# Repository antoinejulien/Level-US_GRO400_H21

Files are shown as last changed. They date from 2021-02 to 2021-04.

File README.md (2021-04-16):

# Level_US_GRO400_H21
This is an opensource project made by a team of undergratuate students from Sherbrooke University. This project is basically a self-leveling platform controled with an embedded system. Our purpose is to create a platform that will automatically balance itself according to the acceleration applied. For example, this project could be applied on boat's tables that could have to follow big waves movements. The table could then automatically balance so nothing would be spilled. We are also working on a manual mode that could allow full user control. This feature is still in progress.

## READMEs
We chose to create a README for every major section. This way, information is separated and easier to find. You can always click the next few links to get directly there :
  - [Code README](Code/README.md)
  - [Electronics README](Electronics/README.md)
  - [Mechanics README](Mechanics/README.md)

## Final prototype
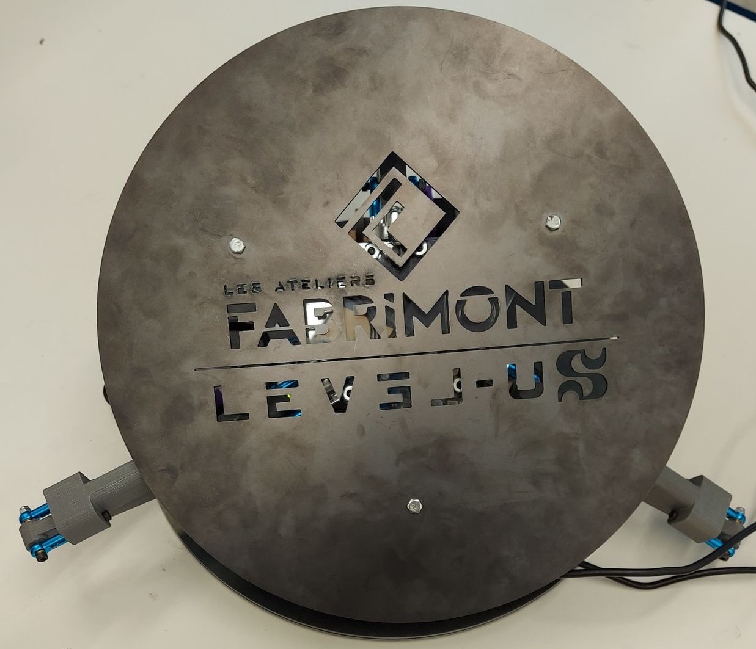
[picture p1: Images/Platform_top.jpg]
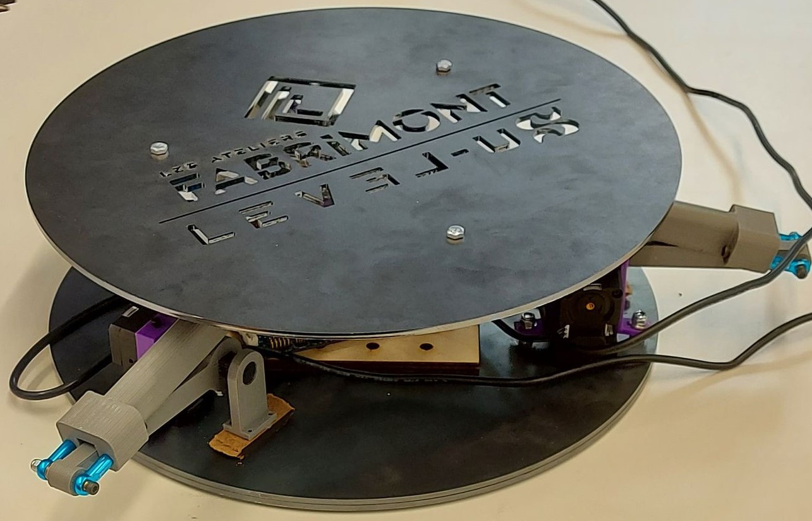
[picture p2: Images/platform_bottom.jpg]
 

## How to install the Python virtual environment (on Windows)

1. If not already installed, install Python 3 from the [Python website](https://www.python.org/downloads/).
2. Add the root directory of your Python installation (i.g. Python38) and the sub-directory *Scripts* to your system's environment variables [Settings > System > About > System info > Advanced system settings > Environment variables > Path (under user variables)].
3. Open a command prompt and navigate to the project folder. *You can run `python --version` and `pip --version` to make sure Python and pip are installed correctly*.
4. When in the project's directory you can create a new virtual environment using `python -m venv name_venv`.
5. Like for your system installation of Python, add your venv folder and it's *Scripts* sub-directory to your system's environment variables (like step 2).
6. To be able to use your different Python installation, you can create a .bat file with a different name i.g. python_myproject.bat.
7. Open this .bat file using a text editor and write `%~dp0python %*`.
8. In your command prompt you can now use python_myproject to refer to this specific installation.
9. To activate the venv, while in the project directory run `my_venv\Scripts\activate`.
10. Install the required module by running `pip install -r /path/to/requirements_win.txt`. *The requirements_win.txt file should be downloaded with the repository in the main project folder*.

## How to install the Python environment (on Linux)

1. If not already installed, download and install the latest Python 3 version from the [Python website](https://www.python.org/downloads/source/) following [this guide](https://www.dummies.com/programming/python/how-to-install-python-on-a-linux-system/).
2. Install pip using `sudo apt install python3-pip`
3. Install venv using `sudo appt install python3-venv`
4. Open a command prompt and navigate to the project folder. *You can run `python3 --version` and `pip --version` to make sure Python and pip are installed correctly on Linux python*.
6. When in the project's directory you can create a new virtual environment using `python3 -m venv name_venv`.
7. Go to the newly environment folder using `cd name_venv\bin` and run `source activate` to activate the venv.
8. Run `pip install -r /path/to/requirements_linux.txt` to install the required modules. *The requirements_linux.txt file should be downloaded with the repository in the main project folder*.

### Add the venv to .gitignore

We do not want the venv to be pushed to Github in case of a push.

1. Open a git bash and navigate to your project directory linked with Github.
2. Run `echo 'my_venv' >> .gitignore` to add the venv to .gitignore. 

This way, the next you commit a change, the files in .gitignore will not be commited.

## CFFI library build

The CFFI module needs to be rebuilt for every computer so you will have to update the values of your dynamic model and rebuild the library.
1. In [anglePlaqueToAngleMoteur.c](https://github.com/antoinejulien/Level-US_GRO400_H21/blob/master/Code/Python/modules/anglePlaqueToAngleMoteur_c/anglePlaqueToAngleMoteur.c), from line 770 you will have the different dimensions to modify for your model, the length of the first arm is longueurBras1.contents on line 774, length of arm 2 is longueurBras2.contents on line 777 and the radius from the center of the platform to the second arm is rayonDistanceAncrageEtPivot.contents on line 780. All these values are in milimeters.
2. Once the values are updated you will need to install Microsoft [Visual C++ 14.0](https://visualstudio.microsoft.com/visual-cpp-build-tools/) or higher to rebuild the library.
3. Once it is installed, you can run `python_myproject angleLibBuild.py`in your command line to rebuild the library.
4. The program should now be able to run.

## Contact us

To contafct us leave a message below and one of us will try to get back to you.

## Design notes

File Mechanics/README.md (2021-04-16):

## Cad design:

  The cads of all prototypes are presented in this section. All parts and assembly are made on SolidWorks 2020.
  
  Here are the list of all the materials used for the final prototype :
  
      - Wooden parts:
      
          Platforms
          
      - 3D printed plastic parts:
      
          Motor's holders
          
          Motor's axles holders
          
          Motor's arms
          
      - Molded plastic:
      
          Motor's frames
          
          Top pivot's holders
          
      - Metal:

          Every screws and nuts (M3)
          
          Base and top platform
          
          Ball Joints (M3)
      
 Notes:   
 
   OpenCR and RaspberryPi are approximated by the middle box.

## Dynamic modelisation:

  The MG code is used to generate dynamics equations and a matlab code wich is then used with an extension
  (matlab coder) to provide the .c or .cpp files wich will be implemented with the openCR card.

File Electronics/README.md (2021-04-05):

# Electronic components used:

  -Rasberry PI : https://www.raspberrypi.org/documentation/hardware/raspberrypi/bcm2711/rpi_DATA_2711_1p0_preliminary.pdf
  
  -Open CR : https://emanual.robotis.com/docs/en/parts/controller/opencr10/
  
  -3x Dynamixel XL-430-W250-T : https://emanual.robotis.com/docs/en/dxl/x/xl430-w250/
  
  -MPU6050 : https://invensense.tdk.com/wp-content/uploads/2015/02/MPU-6000-Datasheet1.pdf

# Wiring: 
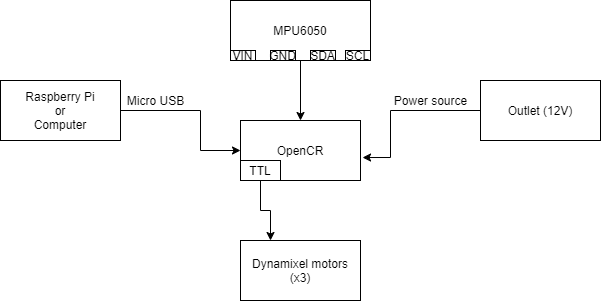
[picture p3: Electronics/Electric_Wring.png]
Wiring


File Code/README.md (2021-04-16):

# Code READ ME

## GUI

The GUI is built using the Kivy2.0 module for Python 3.6. The resolution of the screen was originally set to 480x320 because it is the resolution of the touch scren that would be used eventually, but it is still not implemented. The GUI is scallable so the window can be bigger and the layout will stay the same.
The app contains 3 windows:
1. Menu, boot window and used to acces the other windows. It also allows to see the state of the serial port connection. If the port is not connected, a pop-up will appear to block the acces to that window.
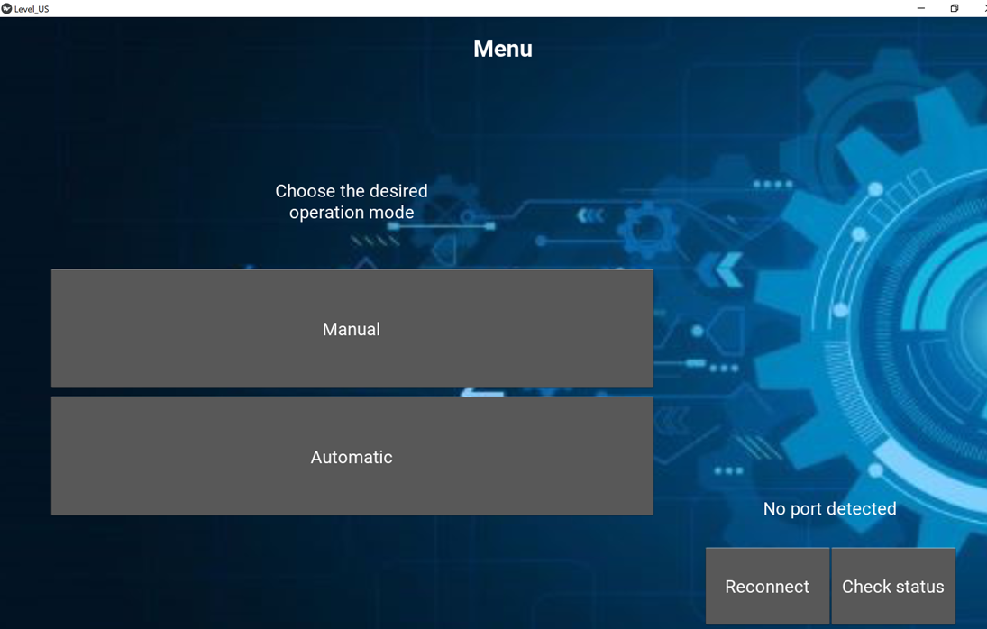
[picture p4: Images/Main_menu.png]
  
2. Manual Window, used to manually control the movement of the platform to allow easy testing.
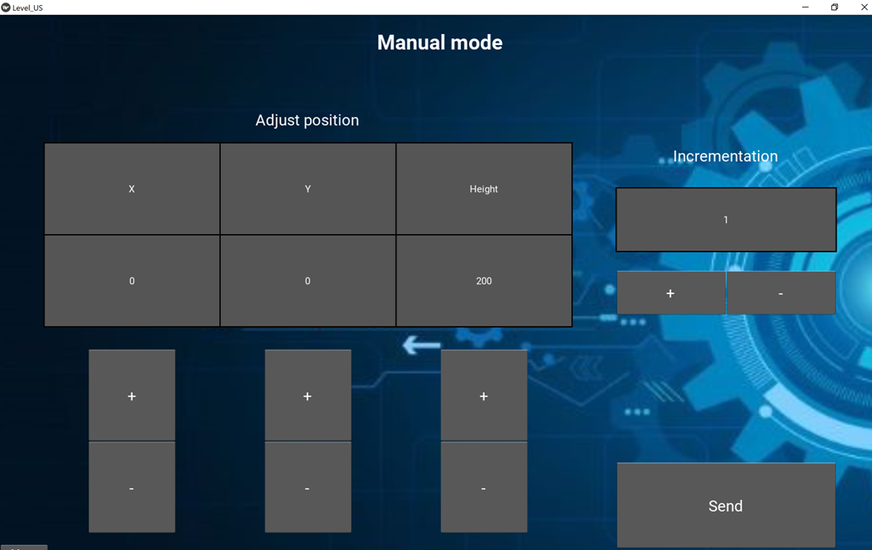
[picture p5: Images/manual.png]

3. Automatic Window, allows to start and stop the automatic control of the platform. The values read by the OpenCR and the motor angles sent are also displayed on the screen.
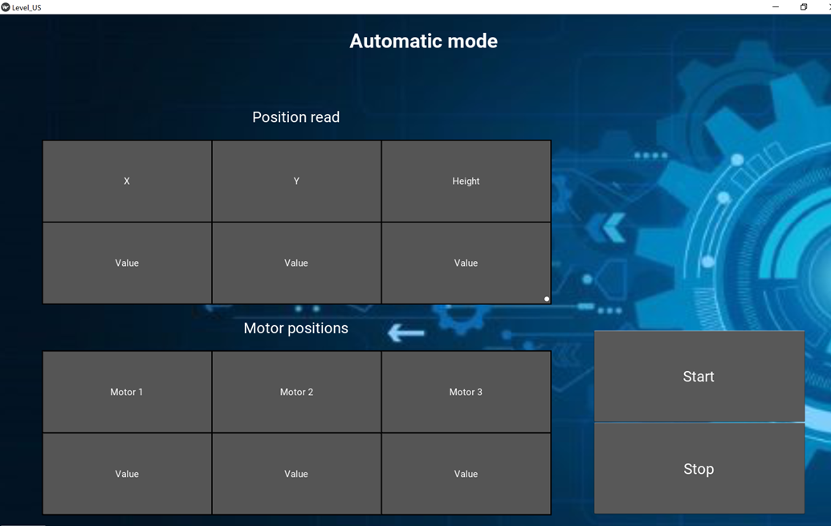
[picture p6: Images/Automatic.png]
  
NOTE: If the serial connection is lost during the use of the automatic mode, it will stop and return to the menu.

## OpenCR code

It is recommended to use the desktop Arduino IDE to upload the .ino code into the OpenCR. You can follow this link https://emanual.robotis.com/docs/en/parts/controller/opencr10/ for a step by step download (section 4). In the Arduino IDE app, you will also need to download the Dynamixel library. To do so :
  - Go to Tools -> Manage libraries ... -> Make sure that option all is selected in both boxes -> Type Dynamixel2Arduino and download the library.

If there are any issues, the library will still be available in the corresponding foler ([Libraries folder](Arduino/libraries)). You will then be able to use the library to communicate easily with the dynamixel motors. There are a few example codes in the File -> Example -> OpenCR section in the arduino IDE.

The MPU6050 libraries and all libraries attached were taken from another opensource github project. The link to the GitHub page is : https://github.com/rfetick/MPU6050_light

## Communication

The app is the high-end of the program, it sends commands to the OpenCR platform for the command type and positionning. The openCR communicates information about the sensors and the motors. Information are encoded and decoded on both end. All communication is done by serial port. 

## Code Specifications

Make sure that the motors are labeled correctly from 1 to 3 in the arduino code. Also, motor 1's arm should be aligned with the x openCR IMU rotating axis. Also, as for the MPU6050, the code to retreive angles was written and commented in the openCR code. We wanted to make a PID on the position and the angle, but we didn't have enough time.

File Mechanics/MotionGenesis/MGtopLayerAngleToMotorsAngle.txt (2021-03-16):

% MotionGenesis file:  MGTemplateBasic.txt
% Copyright (mot2) 2009-2020 Motion Genesis LLC.  Only for use with MotionGenesis.
%--------------------------------------------------------------------
%   Physical objects.
NewtonianFrame  plaqueBas                % Newtonian reference frame
RigidBody       mot1,mot2,mot3,	Bras1Debut,Bras2Debut,Bras3Debut,	Bras1Fin,Bras2Fin,Bras3Fin,	PlaqueTop  
%plaqueBas = plaque bas
%BCD = moteur
%EFG = bras 1
%HLM = bras 2
%NOP = joint pivot
%PlaqueTop = plaque top
Point           posMot1(plaqueBas),posMot2(plaqueBas),posMot3(plaqueBas)		%plaque bas

Point			axeMot1(mot1),axeMot2(mot2),axeMot3(mot3)		%moteurs
	
Point			bras1Middle(Bras1Debut),bras2Middle(Bras2Debut),bras3Middle(Bras3Debut)		%Bras 1
	
Point			bras1End(Bras1Fin),bras2End(Bras2Fin),bras3End(Bras3Fin)		%Bras 2 

Point			P1Plaque(PlaqueTop),P2Plaque(PlaqueTop),P3Plaque(PlaqueTop)		%plaque top % 

%--------------------------------------------------------------------
%   Mathematical declarations.

Variable	angleBras1Middle'',angleBras2Middle'',angleBras3Middle''			%angle bras 2

choice = 1 	% 1= positionPlaqueInputAngleMoteurOutput
			% 2= positionAngleMoteurInputPlaqueOutput
if(choice == 1){
	Variable   	angleMot1'',angleMot2'',angleMot3''			%angle bras 1
	specified 	anglePlaqueTop_x'',anglePlaqueTop_y''      	%angle plaque top
	%specified	eR0'',eR1'',eR2'',eR3''
	specified 	hauteurPlaqueTop''		%position des centres de masse de la plaque du haut par rapport plaque du bas
	Variable 	anglePlaqueTop_z'', distancePlaqueTop_x'',distancePlaqueTop_y''
}
if(choice == 2){
	specified  	angleMot1'',angleMot2'',angleMot3''			%angle bras 1
	variable 	anglePlaqueTop_x'',anglePlaqueTop_y'',anglePlaqueTop_z''      	%angle plaque top
	Variable 	distancePlaqueTop_x'',distancePlaqueTop_y'',hauteurPlaqueTop''		%position plaque du haut par rapport plaque du bas
}

constant	rayonDistanceAncrage = 133.33 mm	%distance entre Bras2Fin'ancrage de la plaque du haut et du pivot par rapport au centre de masse de la plaque
constant 	rayonDistanceMoteur = (133.33+15) mm
constant	hauteurAxeMoteur = 28.63 mm
constant 	longueurBras1 = 3 in
constant	longueurBras2 = 4 in
constant	rayonDistanceAncrageEtPivot = (133.33+15) mm

%--------------------------------------------------------------------

%   Mass and inertia properties.
%PlaqueTop.SetMass(mR = 44.39 grams)
%chargeAppliquerSurPlaque.setMass(masseCharge)
%PlaqueTop.setInertia(Rcm, IRxx = 78730.95 grams*mm^2 , IRyy = 78730.95 grams*mm^2, IRzz = 157163.35 grams*mm^2)

%--------------------------------------------------------------------
%   Rotational kinematics.
mot1.RotateZ(plaqueBas, 0*ConvertUnits(deg,rad))
mot2.RotateZ(plaqueBas, -120*ConvertUnits(deg,rad))
mot3.RotateZ(plaqueBas, 120*ConvertUnits(deg,rad))

Bras1Debut.RotateX(mot1,angleMot1)
Bras2Debut.RotateX(mot2,angleMot2)
Bras3Debut.RotateX(mot3,angleMot3)

Bras1Fin.RotateX(Bras1Debut,-angleBras1Middle)
Bras2Fin.RotateX(Bras2Debut,-angleBras2Middle)
Bras3Fin.RotateX(Bras3Debut,-angleBras3Middle)

PlaqueTop.Rotate(plaqueBas,bodyXYZ,anglePlaqueTop_x,anglePlaqueTop_y,anglePlaqueTop_z)
%PlaqueTop.setRotationMatrixODE(plaqueBas,Euler,eR0,eR1,eR2,eR3)

%--------------------------------------------------------------------
%   Translational kinematics.
posMot1.Translate(PlaqueBaso,rayonDistanceMoteur*plaqueBasy>)															%position moteur 1
posMot2.Translate(PlaqueBaso,rayonDistanceMoteur*cosDegrees(30)*plaqueBasx> - rayonDistanceMoteur*sinDegrees(30)*plaqueBasy>)	%position moteur 2
posMot3.Translate(PlaqueBaso,-rayonDistanceMoteur*cosDegrees(30)*plaqueBasx> - rayonDistanceMoteur*sinDegrees(30)*plaqueBasy>)	%position moteur 3

axeMot1.translate(posMot1, hauteurAxeMoteur*mot1z>)
axeMot2.translate(posMot2, hauteurAxeMoteur*mot2z>)
axeMot3.translate(posMot3, hauteurAxeMoteur*mot3z>)

bras1Middle.translate(axeMot1, longueurBras1*Bras1Debuty>)
bras2Middle.translate(axeMot2, longueurBras1*Bras2Debuty>)
bras3Middle.translate(axeMot3, longueurBras1*Bras3Debuty>)

bras1End.translate(bras1Middle, -longueurBras2*Bras1Finy>)
bras2End.translate(bras2Middle, -longueurBras2*Bras2Finy>)
bras3End.translate(bras3Middle, -longueurBras2*Bras3Finy>)

PlaqueTopo.translate(PlaqueBaso, distancePlaqueTop_x*plaqueBasx> + distancePlaqueTop_y*plaqueBasy> + hauteurPlaqueTop*plaqueBasz>)
P1Plaque.translate(PlaqueTopo, rayonDistanceAncrageEtPivot*plaqueTopy>)
P2Plaque.translate(PlaqueTopo,rayonDistanceAncrageEtPivot*cosDegrees(30)*plaqueTopx> - rayonDistanceAncrageEtPivot*sinDegrees(30)*plaqueTopy>)	
P3Plaque.translate(PlaqueTopo,-rayonDistanceAncrageEtPivot*cosDegrees(30)*plaqueTopx> - rayonDistanceAncrageEtPivot*sinDegrees(30)*plaqueTopy>)

%--------------------------------------------------------------------
%   Motion constraints (if any).
contrainte[1] = bras1End.GetPosition(PlaqueBaso)-P1Plaque.GetPosition(PlaqueBaso)
contrainte[2] = bras2End.GetPosition(PlaqueBaso)-P2Plaque.GetPosition(PlaqueBaso)
contrainte[3] = bras3End.GetPosition(PlaqueBaso)-P3Plaque.GetPosition(PlaqueBaso)

MotionConstraint[1] = dot(contrainte[1],plaqueBasx>)
MotionConstraint[2] = dot(contrainte[1],plaqueBasy>)
MotionConstraint[3] = dot(contrainte[1],plaqueBasz>)

MotionConstraint[4] = dot(contrainte[2],plaqueBasx>)
MotionConstraint[5] = dot(contrainte[2],plaqueBasy>)
MotionConstraint[6] = dot(contrainte[2],plaqueBasz>)

MotionConstraint[7] = dot(contrainte[3],plaqueBasx>)
MotionConstraint[8] = dot(contrainte[3],plaqueBasy>)
MotionConstraint[9] = dot(contrainte[3],plaqueBasz>)

%MotionConstraint[10] = getAngleBetweenVector(mot1y>, Bras1Debuty>)+getAngleBetweenVector(Bras1Debuty>, Bras1Finy>)+getAngleBetweenVector(Bras1Finy>, axeMot1.GetUnitVector(bras1end))-180*convertunits(deg, rad)
%MotionConstraint[11] = getAngleBetweenVector(mot2y>, Bras2Debuty>)+getAngleBetweenVector(Bras2Debuty>, Bras2Finy>)+getAngleBetweenVector(Bras2Finy>, axeMot2.GetUnitVector(bras2end))-180*convertunits(deg, rad)
%MotionConstraint[12] = getAngleBetweenVector(mot3y>, Bras3Debuty>)+getAngleBetweenVector(Bras3Debuty>, Bras3Finy>)+getAngleBetweenVector(Bras3Finy>, axeMot3.GetUnitVector(bras3end))-180*convertunits(deg, rad)

%--------------------------------------------------------------------
%   Add relevant contact/distance forces.

%chargeAppliquerSurPlaque.AddForce(-Bras3Debut*masseCharge*Az>)

%pause

%--------------------------------------------------------------------

%--------------------------------------------------------------------
%   Solve algebraic equations for list of unknowns.
%Solve( [Dynamics;motionconstraint],qA'',qB'',X'',Fx,Fz,Fwx,Fwz )

% 1= positionPlaqueInputAngleMoteurOutput
% 2= positionAngleMoteurInputPlaqueOutput
if(choice == 1){
% on veut avoir comme reponse hauteurPlaqueTop, anglePlaqueTop_x et anglePlaqueTop_y
	%output angleMot1 deg, angleMot2 deg, angleMot3 deg
	input anglePlaqueTop_x = 0 deg, anglePlaqueTop_y = 10 deg, hauteurPlaqueTop = 92.35 mm
	
	solve( [motionconstraint], distancePlaqueTop_x = 0 mm, distancePlaqueTop_y = 0 mm, anglePlaqueTop_z = 0 mm, angleMot1 = 0 deg, angleMot2 = 0 deg, angleMot3 = 0 deg, angleBras1Middle = 41.19 deg, angleBras2Middle = 41.19 deg, angleBras3Middle = 41.19 deg)
	outputencode angleMot1 deg, anglemot2 deg, anglemot3 deg
	code nonlinear([motionconstraint], distancePlaqueTop_x, distancePlaqueTop_y, anglePlaqueTop_z, angleMot1, angleMot2, angleMot3, angleBras1Middle, angleBras2Middle, angleBras3Middle) var.c(anglePlaqueTop_x deg, anglePlaqueTop_y deg, hauteurPlaqueTop mm)
	pause
	anglePlaqueTop_x
	
	pause
	quit
}
if(choice == 2){
	quit
}

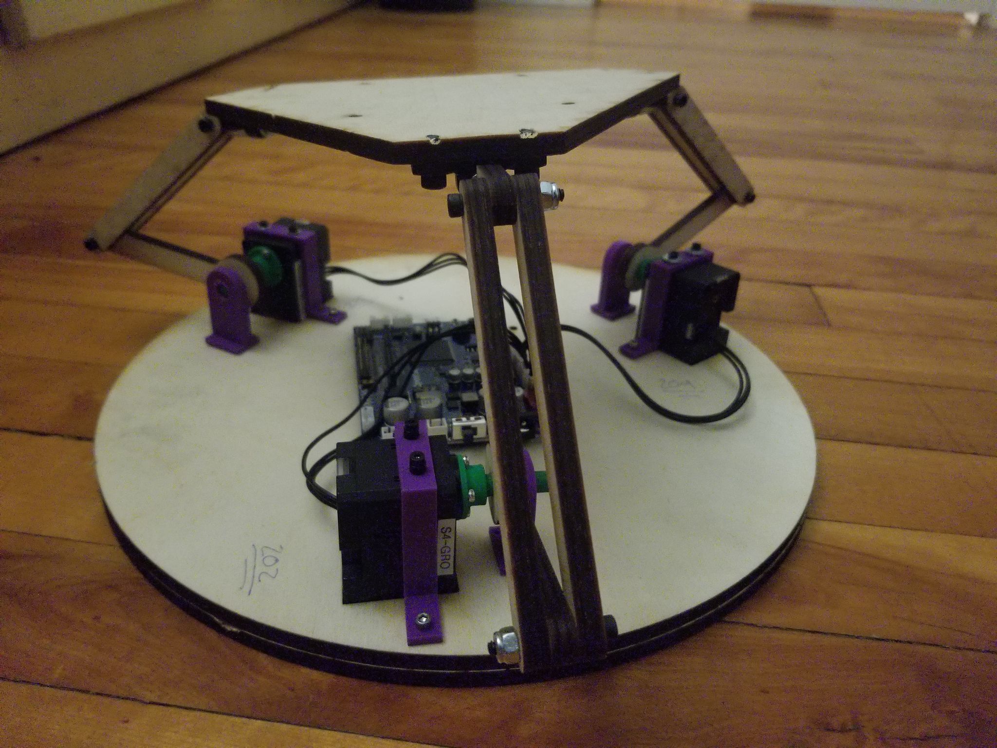
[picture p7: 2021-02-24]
Images/Prototype1.jpg

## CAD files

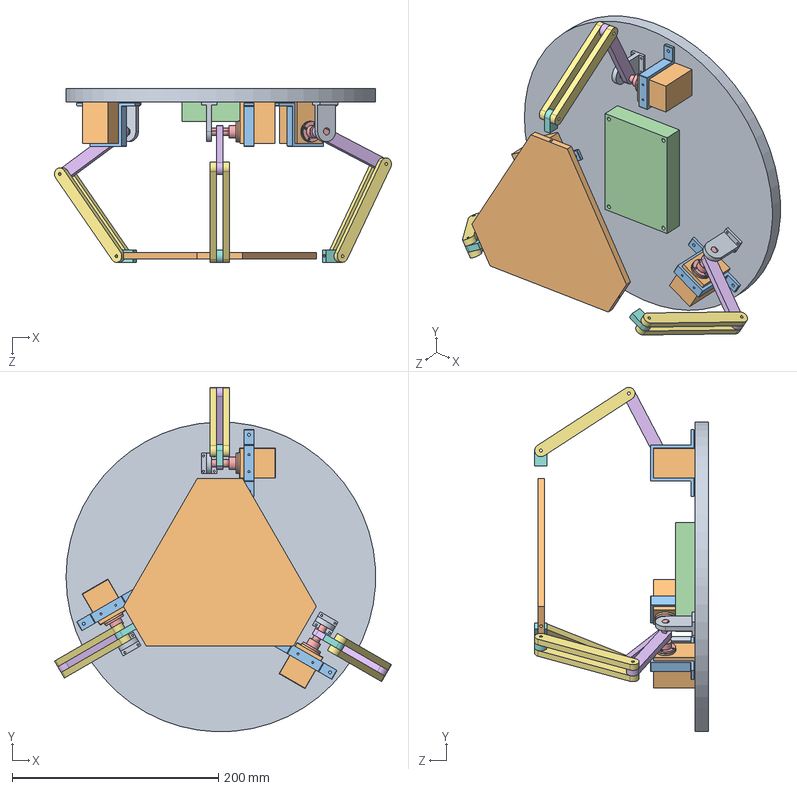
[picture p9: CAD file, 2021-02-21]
Mechanics/CAD_prototype_2/Assemblage2_0.SLDASM
326.5 x 333.7 x 168.3 mm
base2.0
Moteur x 3
fixe_moteurs x 3
OpenCR
Arbre x 3
bras_1 x 3
bras_2 x 6
bras_3 x 3
support_arbre x 3
plateforme

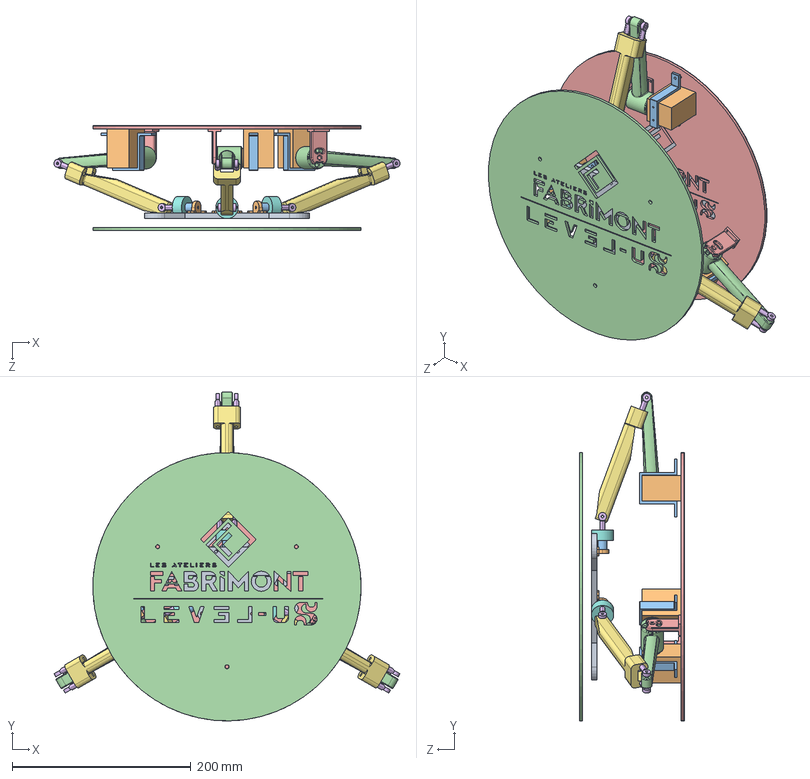
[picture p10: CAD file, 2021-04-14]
Mechanics/Prototype finale/Assemblage.SLDASM
386.8 x 367.6 x 117.0 mm
Moteur x 3
Fixation Moteurs x 3
Bras 1 x 3
Palier lisse x 3
Joints x 12
Bras 2 x 3
Bearing x 3
Plateforme
Fixation Shaft x 3
Shaft x 3
Plateforme Fabrimont
Base Fabrimont

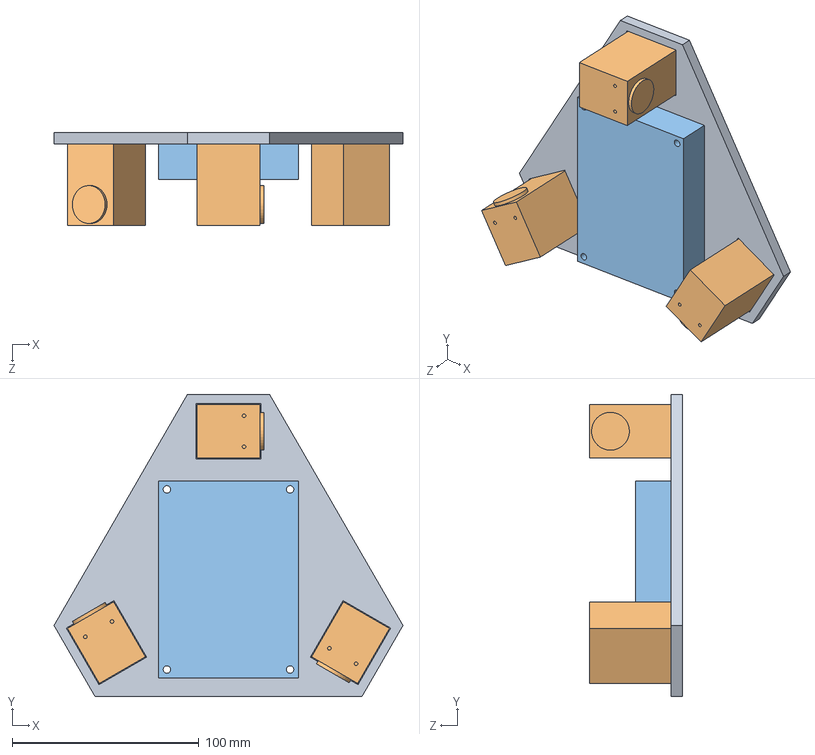
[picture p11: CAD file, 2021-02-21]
Mechanics/CAD_prototype_2/Assemblage1.SLDASM
186.9 x 161.9 x 50.0 mm
Base
Moteur x 3
OpenCR

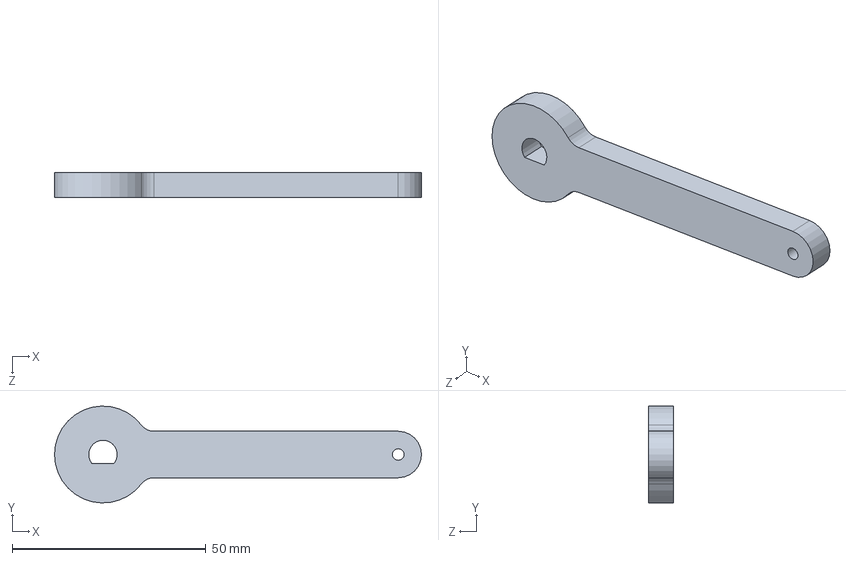
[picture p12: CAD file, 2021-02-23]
Mechanics/CAD_prototype_2/bras_1.SLDPRT
94.7 x 25.0 x 6.35 mm

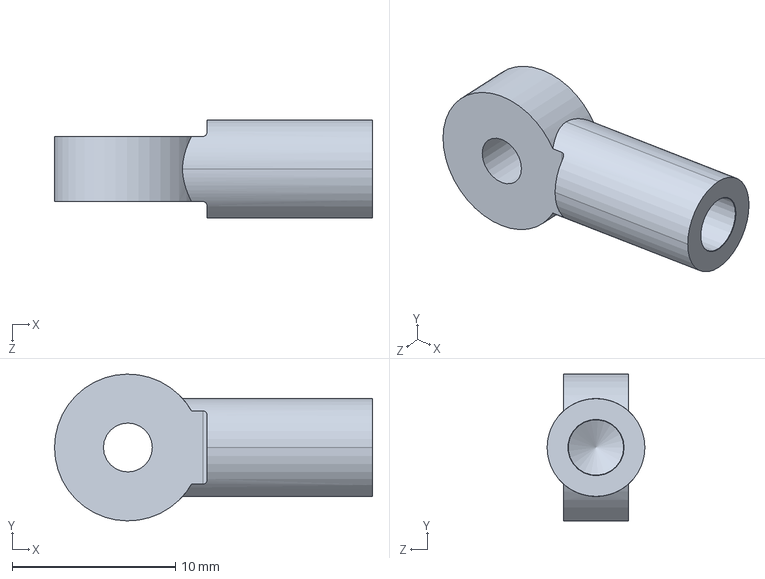
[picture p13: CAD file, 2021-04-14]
Mechanics/Prototype finale/Joints.SLDPRT
19.5 x 9.00 x 6.00 mm

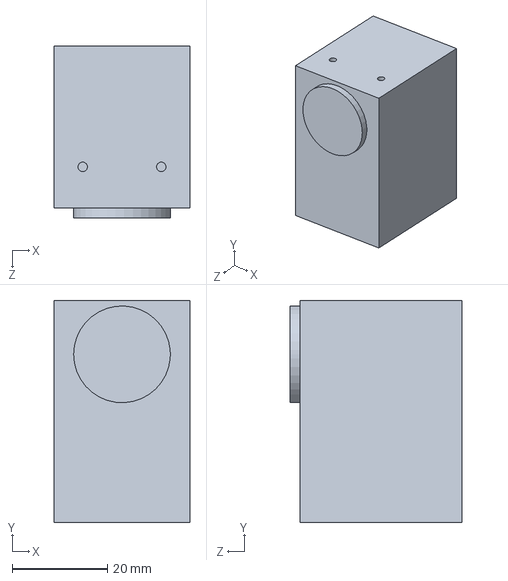
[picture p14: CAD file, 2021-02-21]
Mechanics/CAD_prototype_2/Moteur.SLDPRT
28.5 x 46.6 x 36.0 mm

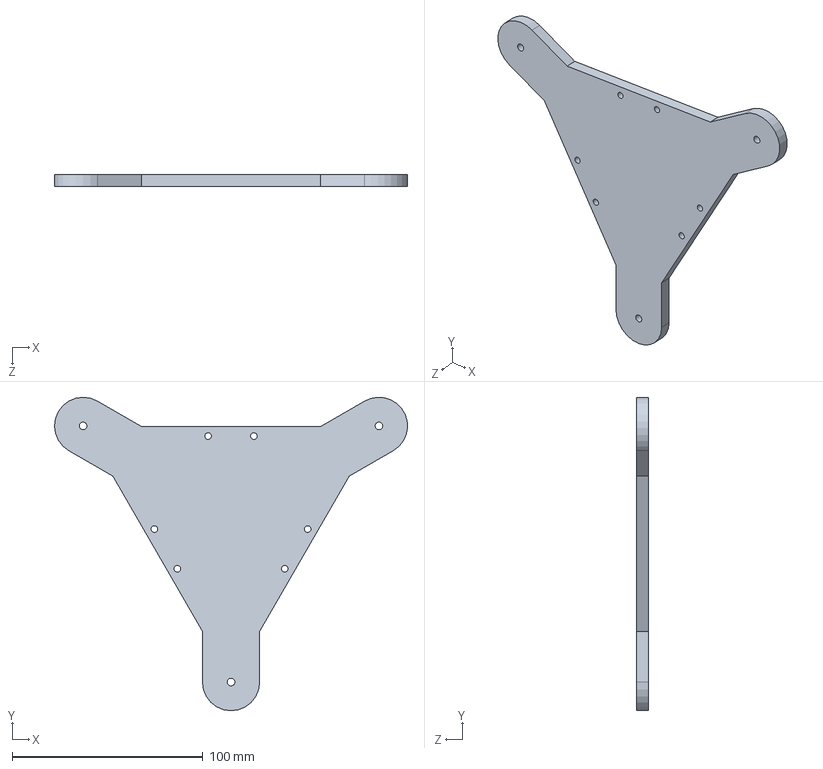
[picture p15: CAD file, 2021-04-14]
Mechanics/Prototype finale/Plateforme.SLDPRT
185.0 x 164.2 x 6.35 mm

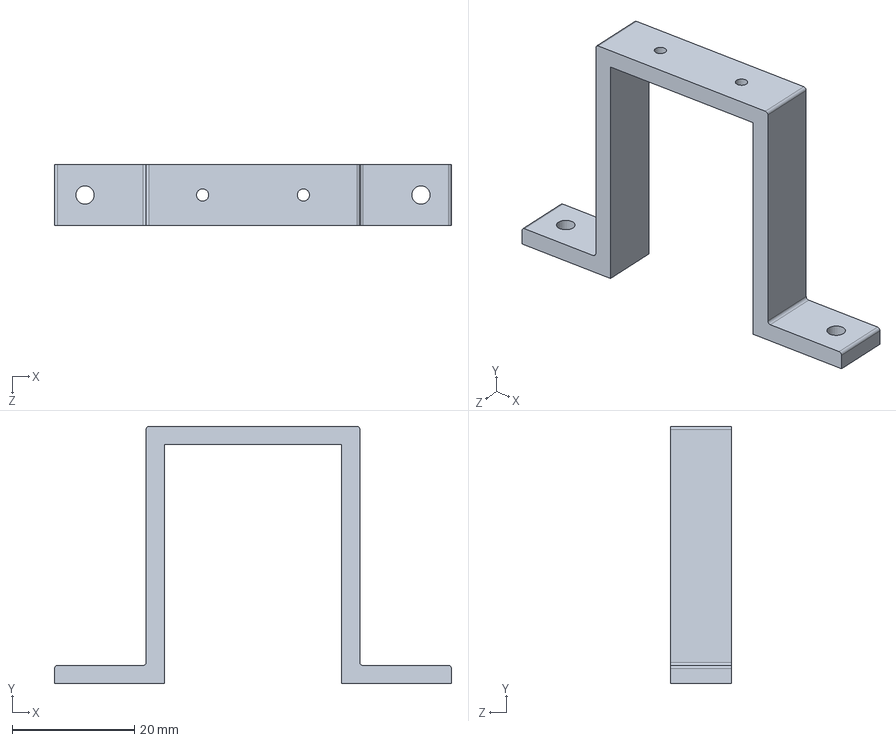
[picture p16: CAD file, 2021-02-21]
Mechanics/CAD_prototype_2/fixe_moteurs.SLDPRT
65.0 x 42.2 x 10.0 mm

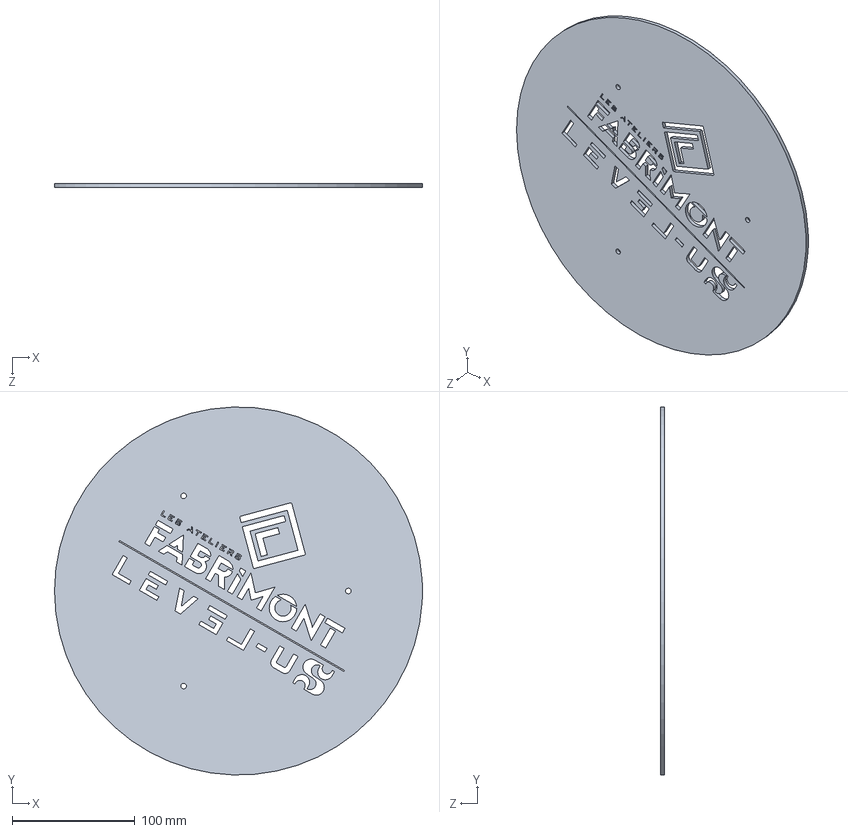
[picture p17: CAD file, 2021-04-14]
Mechanics/Prototype finale/Plateforme Fabrimont.SLDPRT
300.0 x 299.9 x 3.17 mm

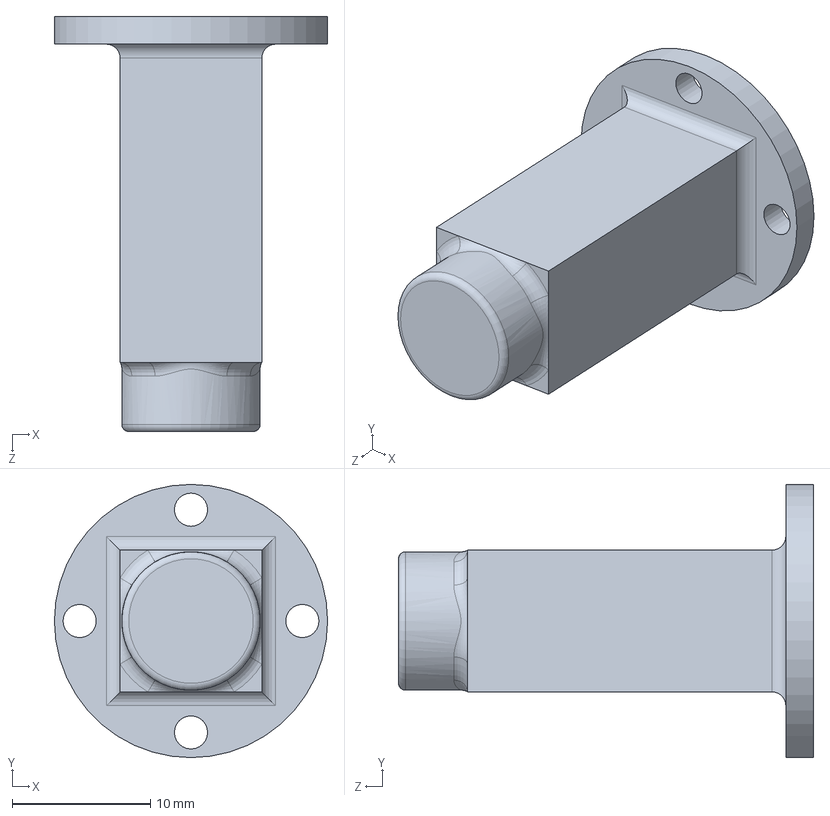
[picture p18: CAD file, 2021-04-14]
Mechanics/Prototype finale/Arbre.SLDPRT
19.8 x 19.8 x 30.0 mm

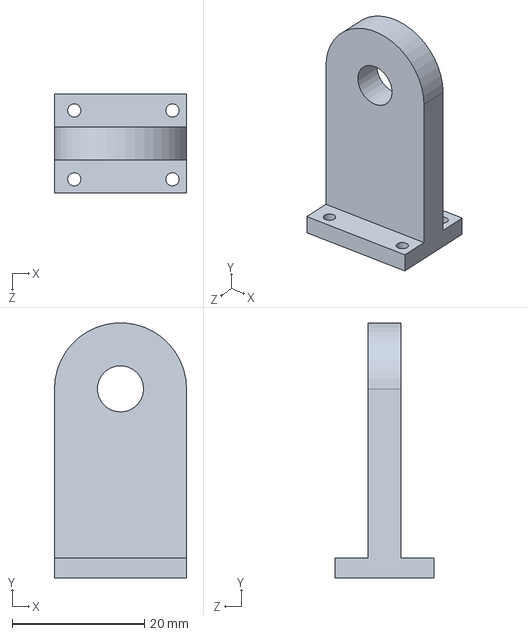
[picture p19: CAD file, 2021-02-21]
Mechanics/CAD_prototype_2/support_arbre.SLDPRT
20.0 x 38.6 x 15.0 mm

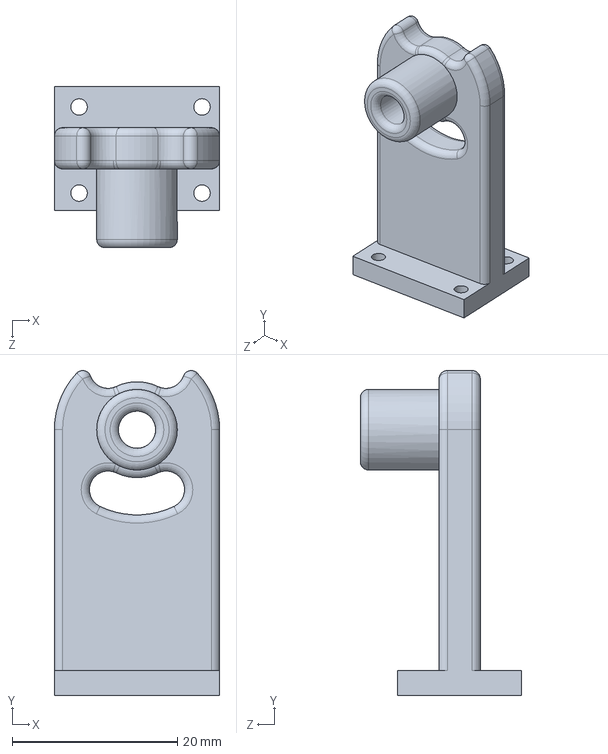
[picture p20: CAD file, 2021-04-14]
Mechanics/Prototype finale/Palier lisse.SLDPRT
20.0 x 39.3 x 19.5 mm

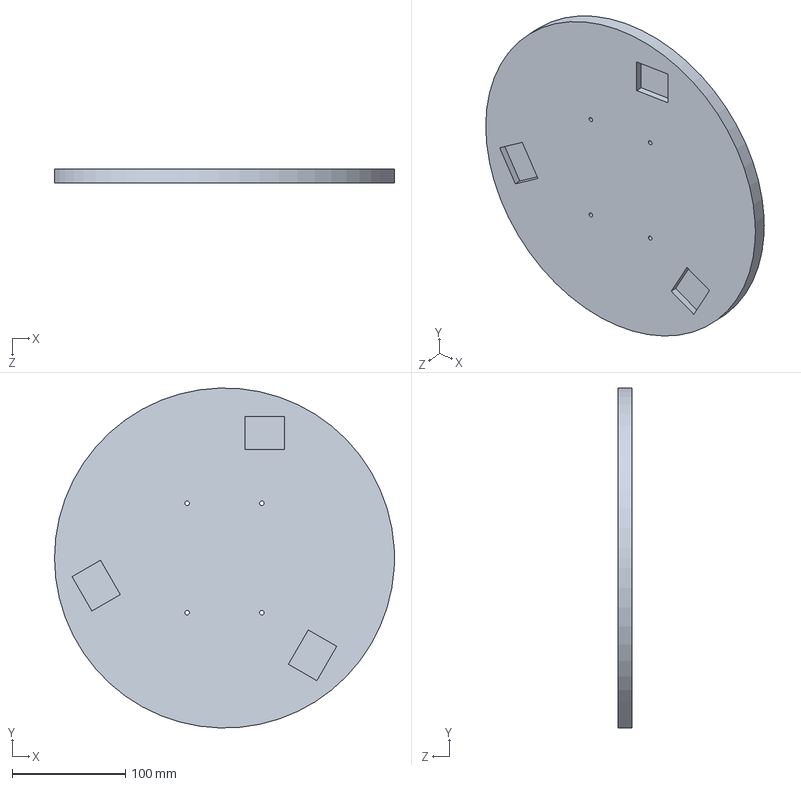
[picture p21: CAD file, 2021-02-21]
Mechanics/CAD_prototype_2/base2.0.SLDPRT
300.0 x 299.9 x 12.7 mm

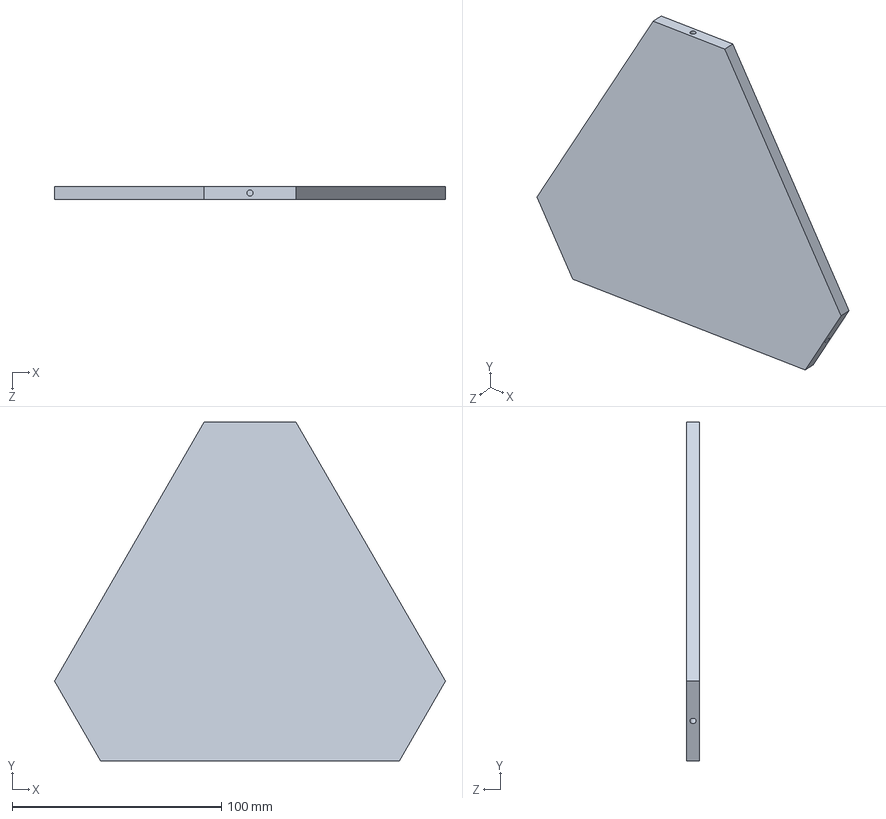
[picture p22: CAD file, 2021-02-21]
Mechanics/CAD_prototype_2/plateforme.SLDPRT
186.9 x 161.9 x 6.35 mm

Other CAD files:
Mechanics/Prototype finale/Moteur.SLDPRT
Mechanics/CAD_prototype_2/bras_2.SLDPRT
Mechanics/Prototype finale/Base Fabrimont.SLDPRT
Mechanics/Prototype finale/Fixation Moteurs.SLDPRT
Mechanics/CAD_prototype_1/3 bras/assemblage.SLDASM
Mechanics/CAD_prototype_1/3 bras/bras 1.SLDPRT
Mechanics/CAD_prototype_1/3 bras/bras 2.SLDPRT
Mechanics/CAD_prototype_1/3 bras/joint bras plaque dessu.SLDPRT
Mechanics/CAD_prototype_1/3 bras/moteur.SLDPRT
Mechanics/CAD_prototype_1/3 bras/plaque base.SLDPRT
Mechanics/CAD_prototype_1/3 bras/plaque top.SLDPRT
Mechanics/CAD_prototype_1/4 bras/assemblage.SLDASM
Mechanics/CAD_prototype_1/4 bras/bras 1 4X.STL
Mechanics/CAD_prototype_1/4 bras/bras 1.SLDPRT
Mechanics/CAD_prototype_1/4 bras/bras 2 4X.STL
Mechanics/CAD_prototype_1/4 bras/bras 2.SLDPRT
Mechanics/CAD_prototype_1/4 bras/dowel 8X.STL
Mechanics/CAD_prototype_1/4 bras/dowel.SLDPRT
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

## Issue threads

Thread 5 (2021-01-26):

Collect electronic material provided

willmarquis, 2021-01-26:
- Michel sera présent au 4028 de 10h à 11h les mercredis matins pour distribuer le matériel et sera disponible à son bureau (C1-4122-7) au besoin dans le reste de la journée entre 11h et 12h et entre 13h30 et 16h.

Closed 2021-02-01.

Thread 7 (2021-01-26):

Print first prototype of the stewart platform

willmarquis, 2021-01-26:
Discussion needed for the number of arms we take.

franktreppromo65, 2021-01-27:
prototype have been printed but we still not sure if tree or four arms are necessary du to the flexion of the plastics arms. a more rigid version should be done.

Closed 2021-01-27.

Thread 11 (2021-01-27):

Wire up a testing bench for the motors

willmarquis, 2021-01-27:

antoinejulien, 2021-02-13:
There is a problem accessing the motors from the Arduino IDE. They seem to be unpingable. Issue needs to be addressed first before creating the testing code.

P-OL, 2021-02-17:
Motors :
DH1901002024 - IP: 224
DH1901002009 - IP: 209
DH1901002015 - IP: 215
DH1901002002 - IP: 202

Closed 2021-02-21.

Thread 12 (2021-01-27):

Write a Arduino code to test the control of the motors

willmarquis, 2021-01-27:

willmarquis, 2021-02-21:
Libraries for OpenCR : https://github.com/ROBOTIS-GIT/OpenCR/tree/master/arduino/opencr_arduino/opencr/libraries

Closed 2021-02-23.

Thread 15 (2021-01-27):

Print rigid prototype from first CAD idea

franktreppromo65, 2021-01-27:

franktreppromo65, 2021-01-27:
Prototype has been printed, but we are still not sure if three or four arms are necessary due to the flexion of the plastic arms. A more rigid version should be done.

franktreppromo65, 2021-01-27:
might be laser-cut

Closed 2021-02-17.

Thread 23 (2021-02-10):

Look up Python struct module for Python/C++ (interface/control) communication

willmarquis, 2021-02-10:

willmarquis, 2021-02-12:
Also look at "asyncio subprocess" module

willmarquis, 2021-02-20:
Article on communication between Arduino and Raspberry Pi

https://roboticsbackend.com/raspberry-pi-arduino-serial-communication/

antoinejulien, 2021-02-22:
Might not be necessary, will be put in backlog.

Closed 2021-03-24.

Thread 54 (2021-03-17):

As a developper team, we need a second prototype

Tristan1208, 2021-03-17:
correct all existing issues of the first one

Closed 2021-04-15.

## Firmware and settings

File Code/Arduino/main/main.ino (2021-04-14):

/************************************
File: OpenCR program for self leveling platform. 
Authors: Level-US team
GitHub: https://github.com/antoinejulien/Level-US_GRO400_H21
Creation date: 15-03-2021
Description: This program sends values from the
IMUs to the raspberry Pi through serial communication
and receives the desired operation mode and the motors
desired angles.
Requirements: This code requires the OpenCR librairies.
************************************/

/*------------------------------ Librairies ---------------------------------*/
#include <DynamixelWorkbench.h>
#include <math.h>
#include <SerialCommunication.h>
#include <OpenCR_IMU.h>
#include "Wire.h"
#include <MPU6050_light.h>

/*--------------------------- Global variables ------------------------------*/
#if defined(__OPENCM904__)
  #define DEVICE_NAME "3"
#elif defined(__OPENCR__)
  #define DEVICE_NAME ""
#endif

SerialCommunication serial;

/* Motors variables */
#define MOTORS_BAUDRATE  57600
#define DXL_ID_1    215
#define DXL_ID_2    202
#define DXL_ID_3    209
DynamixelWorkbench dxl_wb;

int initialMotorsPos = 312; //Angles go from 200 (which will be 0 -20 from the horizontal)
                            //and 90 (which is the vertical)
int motorSpeed = 100;
uint8_t motor1 = DXL_ID_1;
uint8_t motor2 = DXL_ID_2;
uint8_t motor3 = DXL_ID_3;

/* OpenCR IMU variables */
OpenCR_IMU OCRimu_;
float OCRimu_angles[3];

/* MPU6050 variables */
MPU6050 mpu(Wire);
float MPU6050angles[3];

/*-------------------------- Function headers -------------------------------*/
void moveMotors(float motor1_angle, float motor2_angle, float motor3_angle);
void getMPU6050angles(float angles[3]);
int32_t degToInt(float angle);

/*------------------------------- Functions ---------------------------------*/
/*
 * Moves the motors to the desired angle
 * @Param: motor1_angle motor 1 desired angle
 *         motor2_angle motor 2 desired angle
 *         motor3_angle motor 3 desired angle
 */
void moveMotors(float motor1_angle, float motor2_angle, float motor3_angle)
{
  dxl_wb.goalPosition(motor1, degToInt(motor1_angle));
  dxl_wb.goalPosition(motor2, degToInt(motor2_angle));
  dxl_wb.goalPosition(motor3, degToInt(motor3_angle));
}

/*
 * Get the angles from the MPU6050
 * @Param: angles array of float containing the angles
 */
void getMPU6050angles(float angles[3])
{
  angles[0] = mpu.getAngleX();
  angles[1] = mpu.getAngleY();
  angles[2] = mpu.getAngleZ();
}

/*
 * Transfer float angles into int angles
 * @Param: angle angle to transform
 * @Return: return the angle in int32_t
 */
int32_t degToInt(float angle)
{
  return (int32_t)(angle*4097/360);
}
/*-------------------------------- Setup ------------------------------------*/
void setup() 
{
  Serial.setTimeout(5);
  Serial.begin(115200);

  // All commented code are for the second IMU.
  // Uncommet if the MPU6050 is being used. Code
  // will return current angles.
  //  Wire.begin();
  //  
  //  byte status = mpu.begin();
  //  Serial.print(F("MPU6050 status: "));
  //  Serial.println(status);
  //
  //  //Stop everything if could not connect to MPU6050
  //  while(status!=0){ }
  //  
  //  Serial.println(F("Calculating offsets, do not move MPU6050"));
  //  delay(1000);
  //
  //  //Uncomment this line if the MPU6050 is mounted upside-down
  //  mpu.upsideDownMounting = true; 
  //
  //  //MPU6050 gyroscope and accelerometer
  //  mpu.calcOffsets();
  //  Serial.println("Done!\n");

  OCRimu_.initIMU();

  const char *log;
  bool result = false;
  uint16_t model_number = 0;
  float Angle;

  result = dxl_wb.init(DEVICE_NAME, MOTORS_BAUDRATE, &log);

  //Ping motors to make sure they are available
  dxl_wb.ping(motor1, &model_number, &log);
  dxl_wb.ping(motor2, &model_number, &log);
  dxl_wb.ping(motor3, &model_number, &log);

  //Switch motors movement to joint mode
  dxl_wb.jointMode(motor1, motorSpeed, 0, &log);
  dxl_wb.jointMode(motor2, motorSpeed, 0, &log);
  dxl_wb.jointMode(motor3, motorSpeed, 0, &log);

  //Activate torque on the motors
  dxl_wb.torqueOn(motor1);
  dxl_wb.torqueOn(motor2);
  dxl_wb.torqueOn(motor3);

  //Set an initial motor angle
  moveMotors(initialMotorsPos, initialMotorsPos, initialMotorsPos);

  //Delay to let the motors move to the initial position
  delay(2000);
}

/*--------------------------------- Loop ------------------------------------*/
void loop() 
{   
  float commands[3];
  
  OCRimu_.updateAngles();
  //mpu.update();

  if(Serial.available() > 0) 
  {
    if(serial.serialDecoder(commands) == 0)
    {
      moveMotors(commands[0], commands[1], commands[2]);
    }
    else
    {
      //Update IMU angles before sending the values
      OCRimu_.updateAngles();
      OCRimu_.getAngles(OCRimu_angles);

      //mpu.update();
      //getMPU6050angles(MPU6050angles);
      
      serial.serialEncoder(OCRimu_angles);   
    }
  }
}

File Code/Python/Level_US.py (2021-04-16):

import time
import serial

from modules import comm
from modules.anglePlaqueToAngleMoteur_c import getAngles_cffi
from modules.anglePlaqueToAngleMoteur_c.getAngles import getAngles

from kivy.app import App
from kivy.clock import Clock
from kivy.config import Config
from kivy.core.window import Window
from kivy.lang import Builder
from kivy.properties import ObjectProperty
from kivy.uix.screenmanager import Screen, ScreenManager
from kivy.uix.widget import Widget
from kivy.uix.popup import Popup

Config.set("graphics", "window_state", "maximized")
ser = comm.serialport("COM3", 115200, 1)

height = float(200)

popupWindow = Popup(title ="Port error", content = Builder.load_file("popup.kv"),
                    size_hint =(0.5, 0.5))

class DummyWindow(Screen):
    def on_enter(self):
        Clock.schedule_once(self.switch_screen)

    def switch_screen(self, dt):
        self.manager.current = "menu"

class MenuWindow(Screen):
    def __init__(self, **kwargs): 
        super(MenuWindow, self).__init__(**kwargs)
        self.port_status = ObjectProperty(None)
        self.reco_button = ObjectProperty(None)

    def check_port(self):
        if ser.test_comm() == True:
            self.port_status.text = "Port connected"
            self.reco_button.opacity = 0.75
            self.reco_button.disabled = True
            return True
        else:
            self.port_status.text = "No port detected"
            self.reco_button.opacity = 1
            self.reco_button.disabled = False
            return False

    def reconnect(self):
        global ser
        ser = comm.serialport("COM3", 115200, 1)
        self.check_port()

    def goto_manual(self):
        if ser.test_comm():
            App.get_running_app().root.current = "manual_window"
        else:
            popupWindow.open()
    
    def goto_auto(self):
        if ser.test_comm():
            App.get_running_app().root.current = "auto_window"
        else:
            popupWindow.open()

class ManualWindow(Screen):
    def __init__(self, **kwargs): 
        super(ManualWindow, self).__init__(**kwargs)
        self.x_value = ObjectProperty(None)
        self.y_value = ObjectProperty(None)
        self.h_value = ObjectProperty(None)
        self.i_value = ObjectProperty(None)

        self.qty = 1

    def add(self, axis):
        if axis == "x":
            self.x_value.text = str(int(self.x_value.text) + self.qty)
        elif axis == "y":
            self.y_value.text = str(int(self.y_value.text) + self.qty)
        elif axis == "h":
            self.h_value.text = str(int(self.h_value.text) + self.qty)
        elif axis == "i":
            self.i_value.text = str(int(self.i_value.text) + 1)
            self.qty = int(self.i_value.text)
        
    def substract(self,axis):
        if axis == "x":
            if int(self.x_value.text)-self.qty >= -35:
                self.x_value.text = str(int(self.x_value.text) - self.qty)
        elif axis == "y":
            if int(self.y_value.text)-self.qty >= -35:
                self.y_value.text = str(int(self.y_value.text) - self.qty)
        elif axis == "h":
            if int(self.h_value.text)-self.qty >= 0:
                self.h_value.text = str(int(self.h_value.text) - self.qty)
        elif axis == "i":
            if int(self.i_value.text)-1 >= 1:
                self.i_value.text = str(int(self.i_value.text) - 1)
                self.qty = int(self.i_value.text)

    def send(self):
        sendX = float(self.x_value.text)
        sendY = float(self.y_value.text)
        sendH = float(self.h_value.text)

        anglesMoteurs = getAngles(sendX, sendY, sendH)

        angles = [0, 0, 0]
        for i, angle in enumerate(anglesMoteurs,0):
            angles[i] = round(angle,2)

        ser.encode(0, angles)    

class AutoWindow(Screen):
    def __init__(self, **kwargs): 
        super(AutoWindow, self).__init__(**kwargs)

        self.x_value = ObjectProperty(None)
        self.y_value = ObjectProperty(None)
        self.h_value = ObjectProperty(None)

        self.motor1_value = ObjectProperty(None)
        self.motor2_value = ObjectProperty(None)
        self.motor3_value = ObjectProperty(None)

    def auto_mode(self,dt):
        try:
            global height
            angles = [0, 0, 0]
        

            ser.write(ser.encode(1, angles))
            
            [angleX, angleY] = ser.decode(ser.read())

            anglesMoteurs = getAngles(float(angleX), float(angleY), height)

            for i, angle in enumerate(anglesMoteurs,0):
                angles[i] = round(angle,2)

            ser.encode(0, angles)

            self.update_labels([angleX, angleY, angles[0], angles[1], angles[2]])
        except:
            self.stop_auto()
            App.get_running_app().root.current = "menu"


    def start_auto(self):
        Clock.unschedule(self.auto_mode)
        Clock.schedule_interval(self.auto_mode, 0.075)

    def stop_auto(self):
        Clock.unschedule(self.auto_mode)

    def update_labels(self, data):
        self.x_value.text = str(data[0])
        self.y_value.text = str(data[1])
        self.h_value.text = str(height)
        self.motor1_value.text = str(data[2])
        self.motor2_value.text = str(data[3])
        self.motor3_value.text = str(data[4])


class WindowManager(ScreenManager):
    pass
    def __init__(self, **kwargs): 
        super(WindowManager, self).__init__(**kwargs)

kv_builder = Builder.load_file("Level_US.kv")

class Level_US(App):

    def __init__(self):
        super(Level_US, self).__init__()

        Clock.unschedule(self.check_connection)
        Clock.schedule_interval(self.check_connection, 1)

    def build(self):
        return kv_builder

    def check_connection(self, dt):
        status = App.get_running_app().root.get_screen("menu").check_port()
        if status == True:
            pass
        elif status == False:
            App.get_running_app().root.current = "menu"


if __name__ == "__main__":
    Level_US().run()

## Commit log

2021-01-27 upload of first prototype files
    [assemblage.SLDASM, bras 1 4X.STL, bras 1.SLDPRT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]
2021-02-20 Added new folders
    [assemblage.SLDASM, bras 1 4X.STL, bras 1.SLDPRT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]
2021-02-23 changed cad folder to Mechanics folder and added mG code to folder
    [Arbre.SLDPRT, Assemblage1.SLDASM, Assemblage2_0.SLDASM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]
2021-02-24 Added the arduino folder for ino code
2021-03-27 Refactored the code and added IMU control with motors control
2021-03-29 Added folders for Arduino main and libraries
2021-04-13 Renamed files and folders
    [assemblage.SLDASM, bras 1 4X.STL, bras 1.SLDPRT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]
2021-04-14 added the final cad desing
    [Arbre.SLDPRT, Assemblage.SLDASM, Base Fabrimont.SLDPRT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]
2021-04-14 added pid class
